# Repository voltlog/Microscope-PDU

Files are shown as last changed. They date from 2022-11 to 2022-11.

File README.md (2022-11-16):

# Microscope-PDU
My trinocular microscope has served me well for a few years but it has one annoying thing, the fact that it uses 3 different power adapters: one to supply power to the camera, one for the monitor and another one for the LED lights. This obviously takes up 3 different sockets on my extension lead and creates a mess of wires.

My solution to the problem is this Power Distribution Unit where I have a single 12V input and 3 outputs to feed the required voltages. The board was designed to be configurable, so you have the option of installing a standard footprint dc-dc converter if you need different voltages.

## Links for the additional items you will need
→Enclosure used in the project
https://voltlog.com/y/rpw6u<br />
→DC barrel jack extension leads
Aliexpress https://voltlog.com/y/x1zli

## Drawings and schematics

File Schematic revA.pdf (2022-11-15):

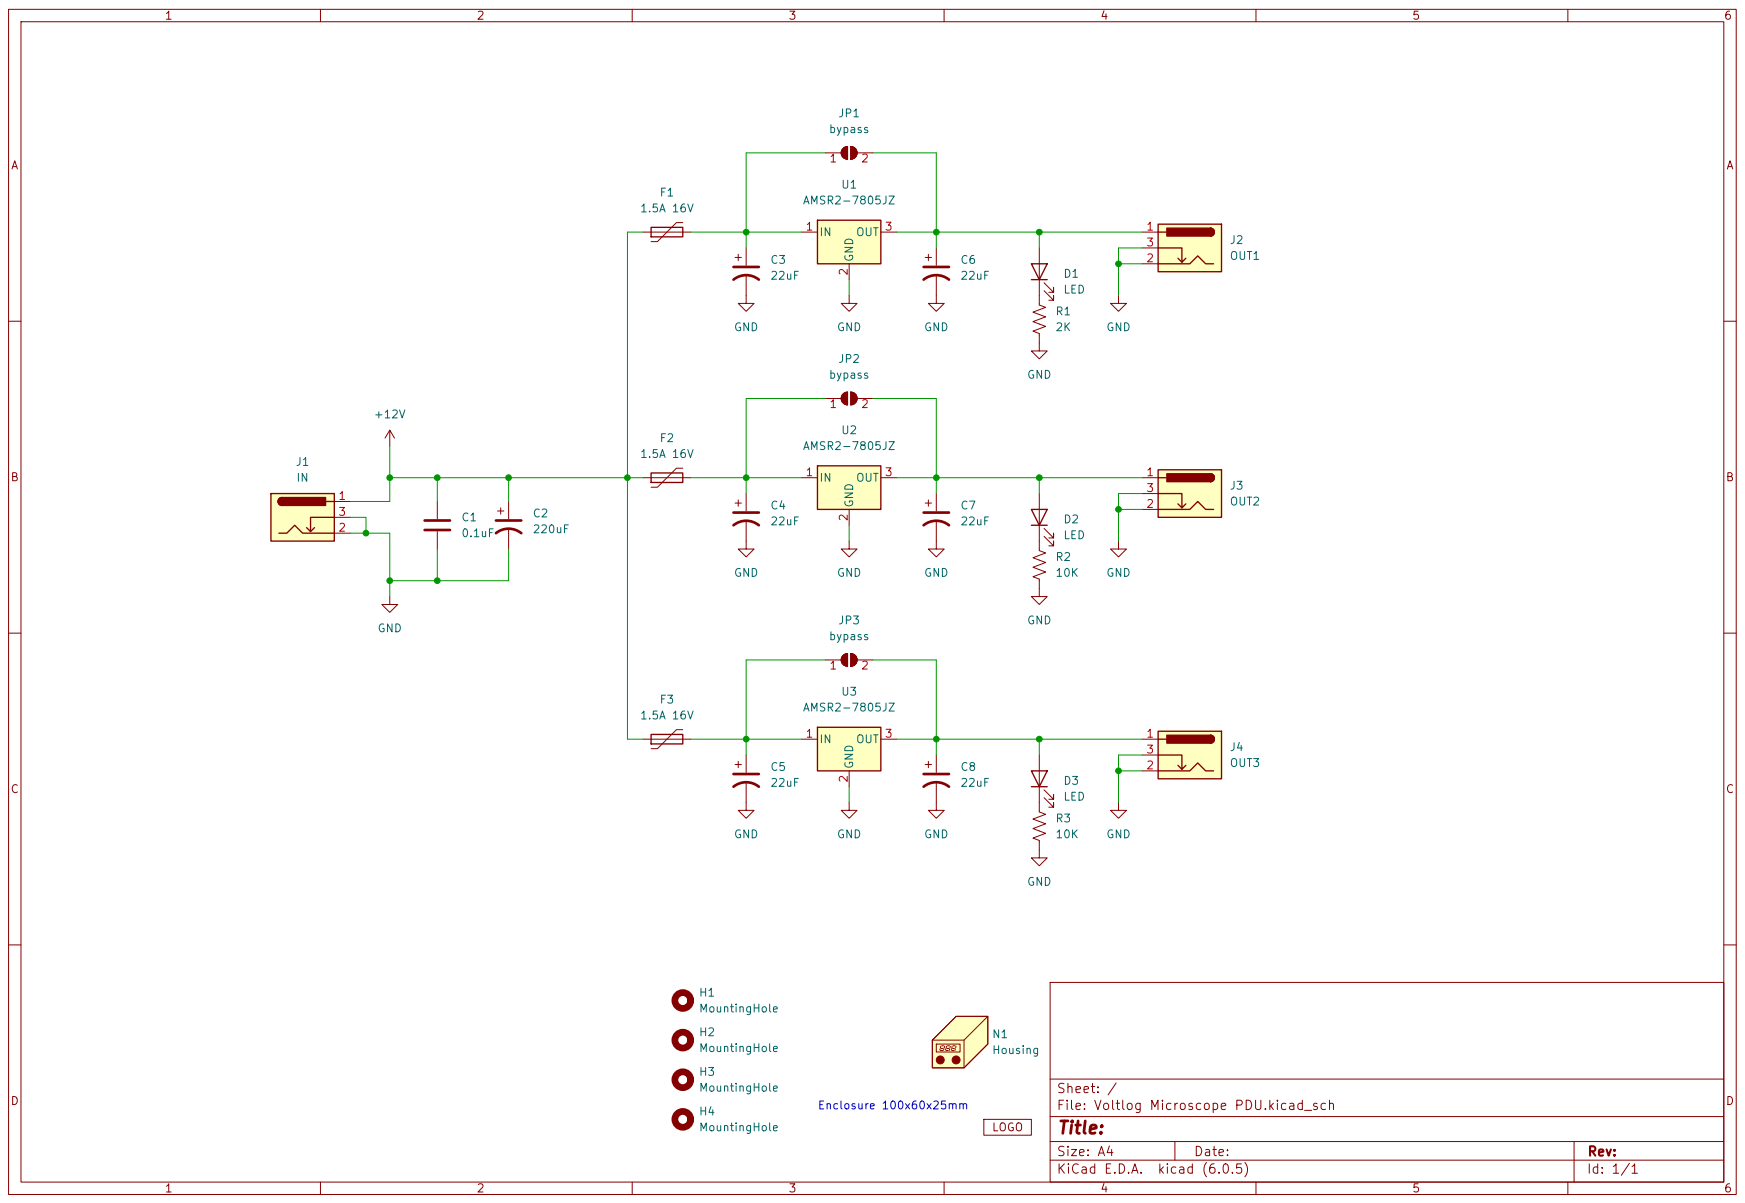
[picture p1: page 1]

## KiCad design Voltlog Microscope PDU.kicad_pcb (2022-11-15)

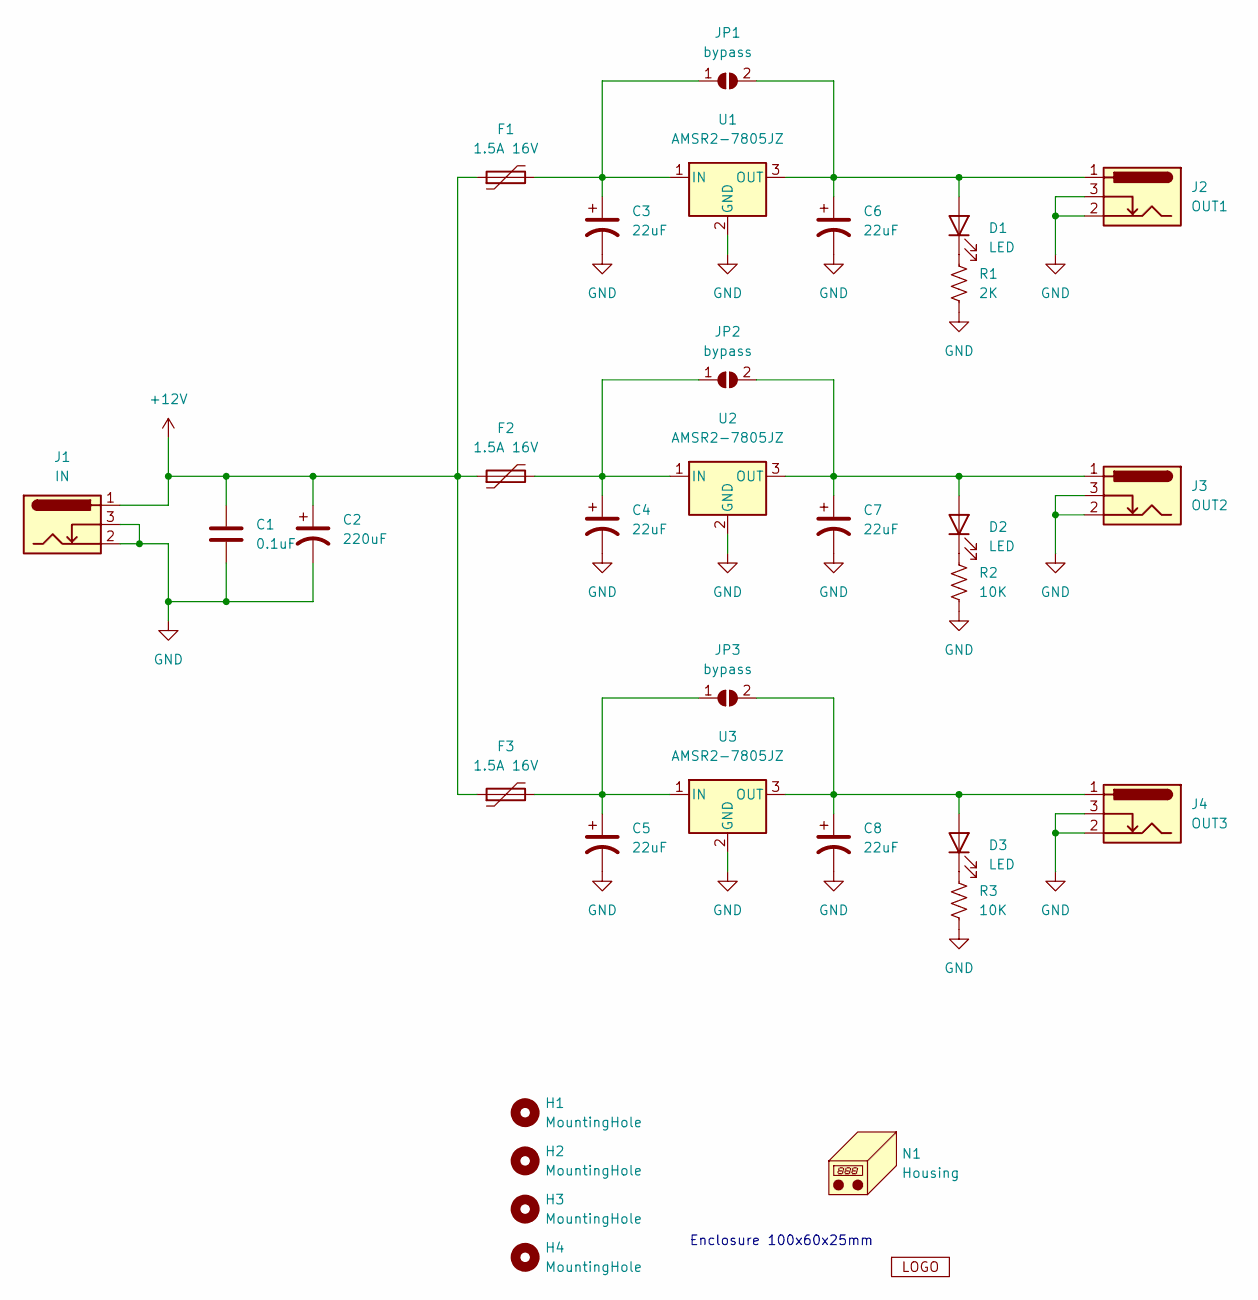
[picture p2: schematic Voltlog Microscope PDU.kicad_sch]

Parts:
C1: 0.1uF; C_0603_1608Metric
C2: 220uF; CP_Elec_8x10
C3, C4, C5, C6, C7, C8: 22uF; CP_Elec_6.3x5.4
D1, D2, D3: LED; LED_0603_1608Metric
F1, F2, F3: 1.5A 16V; Fuse_1812_4532Metric
H1, H2, H3, H4: MountingHole; MountingHole_3.2mm_M3
J1: IN; BarrelJack_CLIFF_FC681465S_SMT_Horizontal; LCSC C2987414
J2: OUT1; BarrelJack_CLIFF_FC681465S_SMT_Horizontal; LCSC C2987414
J3: OUT2; BarrelJack_CLIFF_FC681465S_SMT_Horizontal; LCSC C2987414
J4: OUT3; BarrelJack_CLIFF_FC681465S_SMT_Horizontal; LCSC C2987414
JP1, JP2, JP3: bypass; SolderJumper-2_P1.3mm_Open_RoundedPad1.0x1.5mm
N1: Housing
R1: 2K; R_0603_1608Metric
R2, R3: 10K; R_0603_1608Metric
U1, U2, U3: AMSR2-7805JZ; Converter_DCDC_RECOM_R-78HB-0.5L_THT
V1: VOLTLOG_LOGO; voltlog_mask_5mm

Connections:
+12V: C1.1, C2.1, F1.1, F2.1, F3.1, J1.1
GND: C1.2, C2.2, C3.2, C4.2, C5.2, C6.2, C7.2, C8.2, J1.2, J1.3, J2.2, J2.3, J3.2, J3.3, J4.2, J4.3, R1.1, R2.1, R3.1, U1.2 (GND), U2.2 (GND), U3.2 (GND)
unnamed: C3.1, F1.2, JP1.1 (A), U1.1 (IN)
unnamed: C4.1, F2.2, JP2.1 (A), U2.1 (IN)
unnamed: C5.1, F3.2, JP3.1 (A), U3.1 (IN)
unnamed: C6.1, D1.2 (A), J2.1, JP1.2 (B), U1.3 (OUT)
unnamed: C7.1, D2.2 (A), J3.1, JP2.2 (B), U2.3 (OUT)
unnamed: C8.1, D3.2 (A), J4.1, JP3.2 (B), U3.3 (OUT)
unnamed: D1.1 (K), R1.2
unnamed: D2.1 (K), R2.2
unnamed: D3.1 (K), R3.2

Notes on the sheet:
Enclosure 100x60x25mm

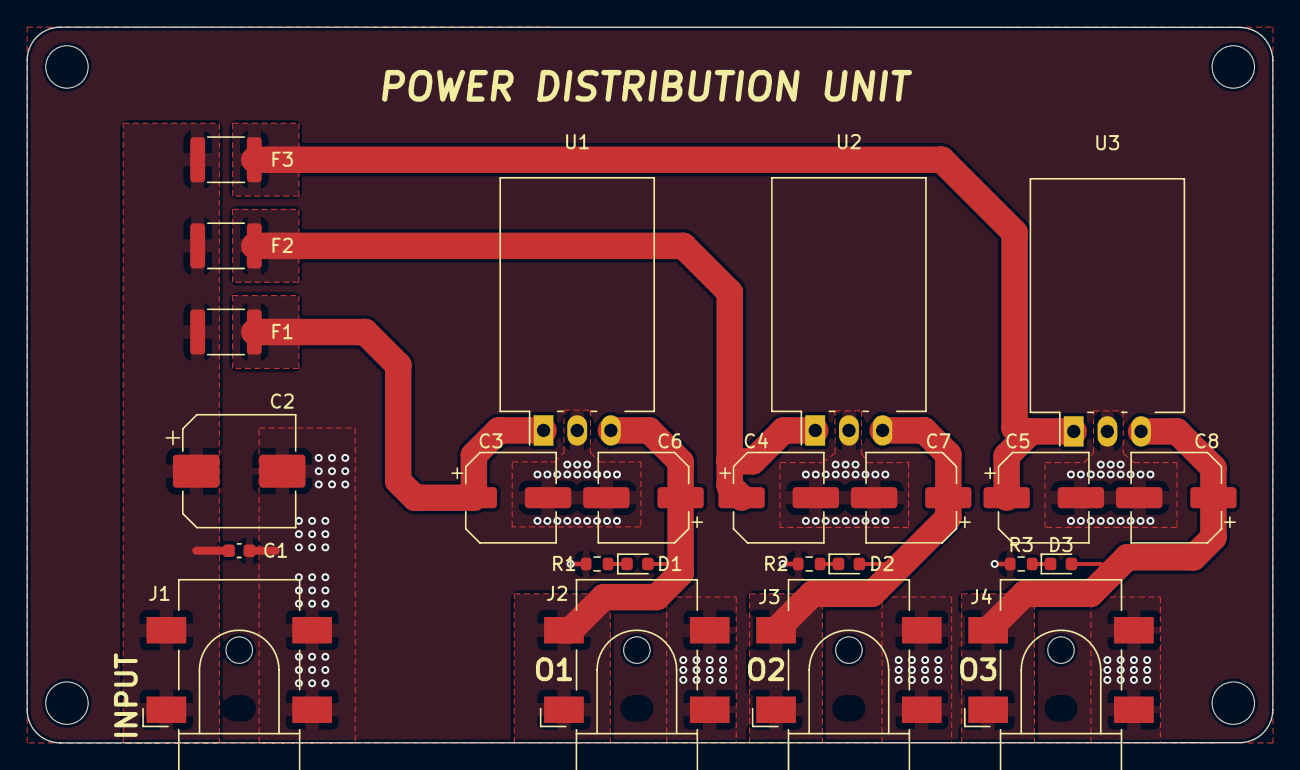
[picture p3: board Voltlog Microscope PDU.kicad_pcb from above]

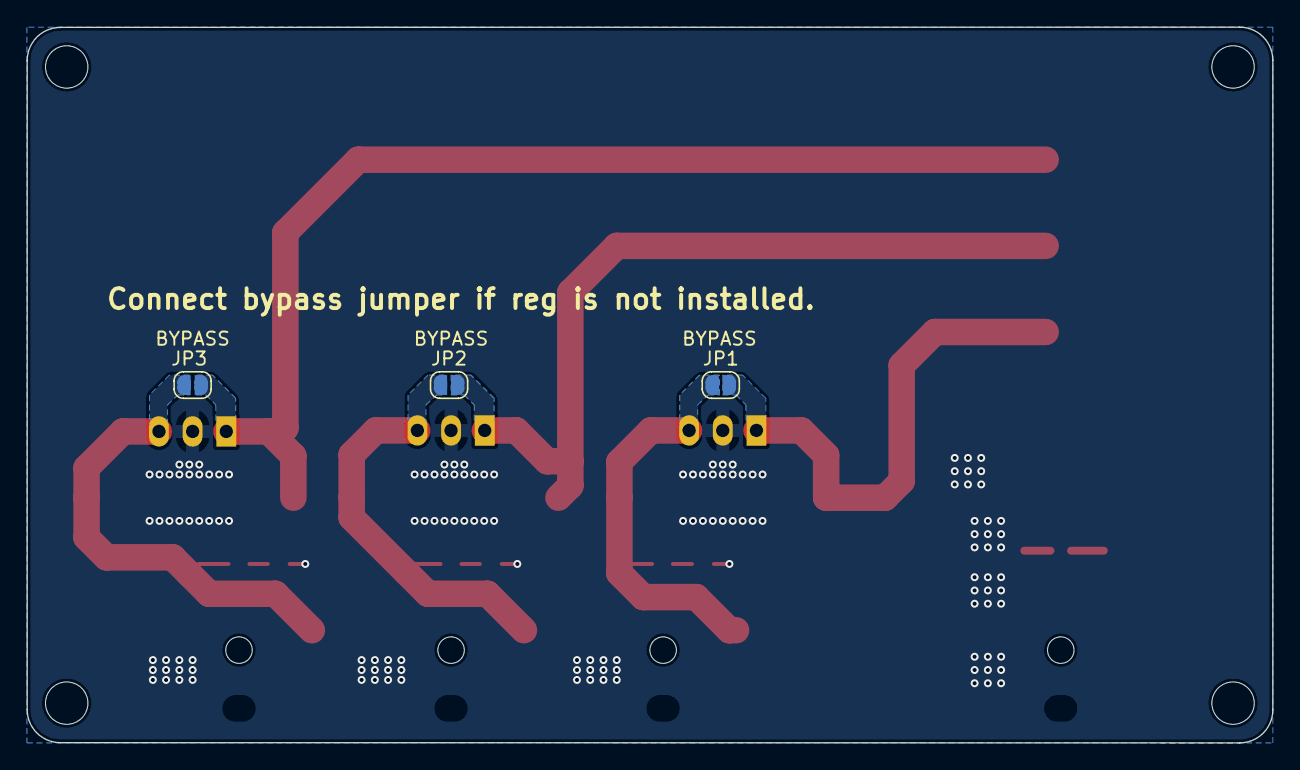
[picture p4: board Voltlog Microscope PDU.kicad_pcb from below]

Board: 2 copper layers, 94.0 x 54.0 mm, 32 parts (3 on the bottom side), 11 nets.
